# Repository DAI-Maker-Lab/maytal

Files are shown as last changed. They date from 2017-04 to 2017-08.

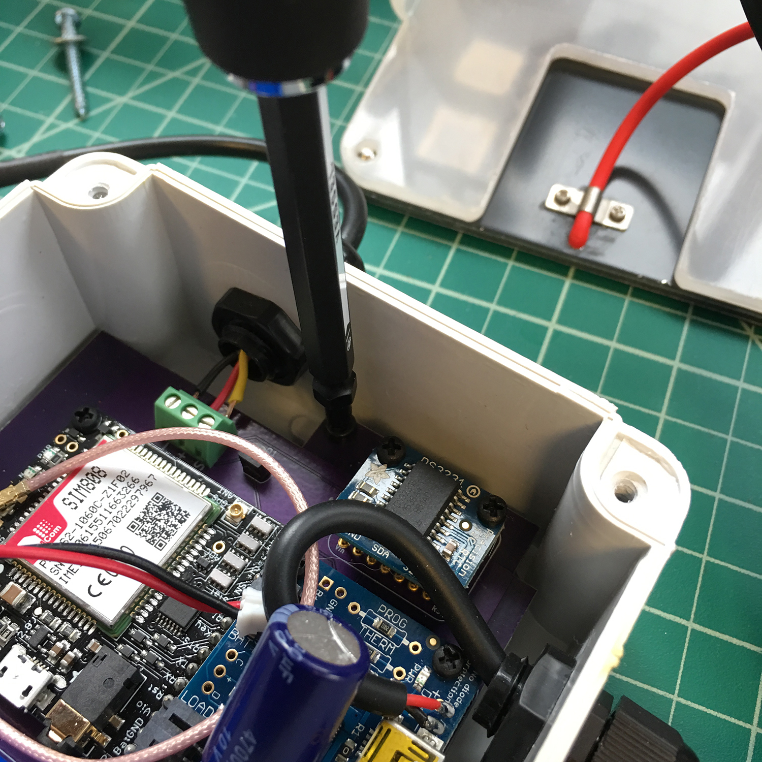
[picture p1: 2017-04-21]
photos/unscrew.jpg

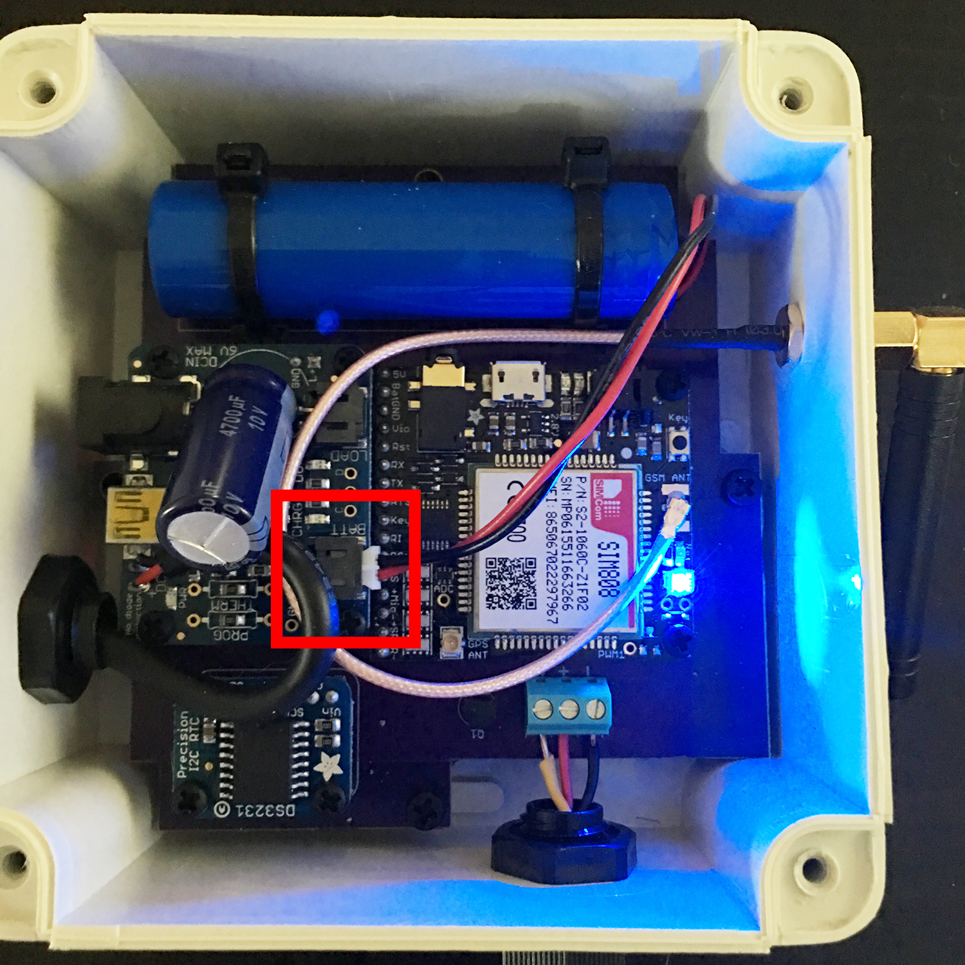
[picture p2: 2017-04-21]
photos/battery.jpg

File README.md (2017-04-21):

# Maytal
Maytal is the temporary name for an open source hardware project that aims to empower local Indonesian water utilities (PDAMs) to track pressure throughout their distribution systems, enabling them to operate more efficiently. The current design is a proof-of-concept prototype to test initial parameters and constraints. The bill of materials cost is about $180 and most parts are available locally in Indonesia.

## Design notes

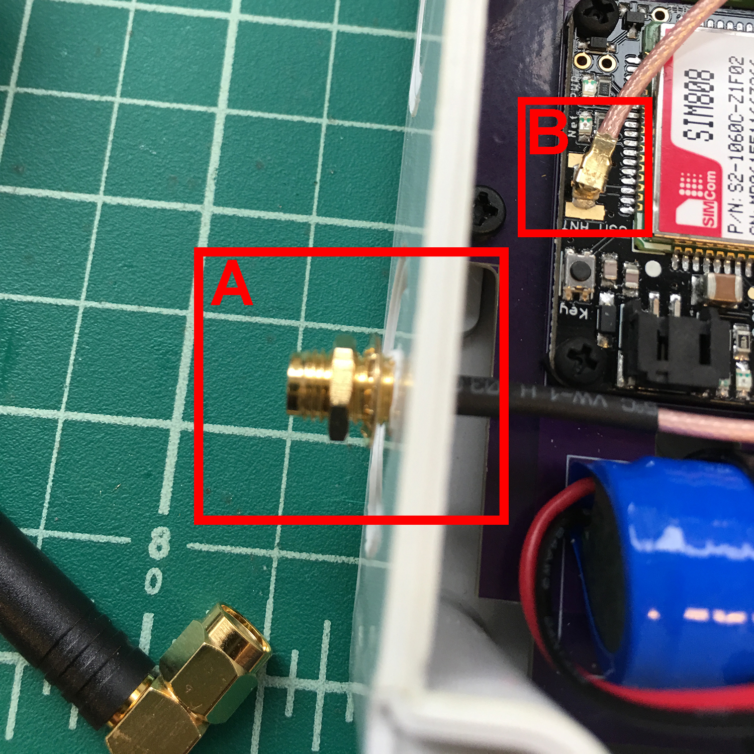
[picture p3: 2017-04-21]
photos/antenna.jpg

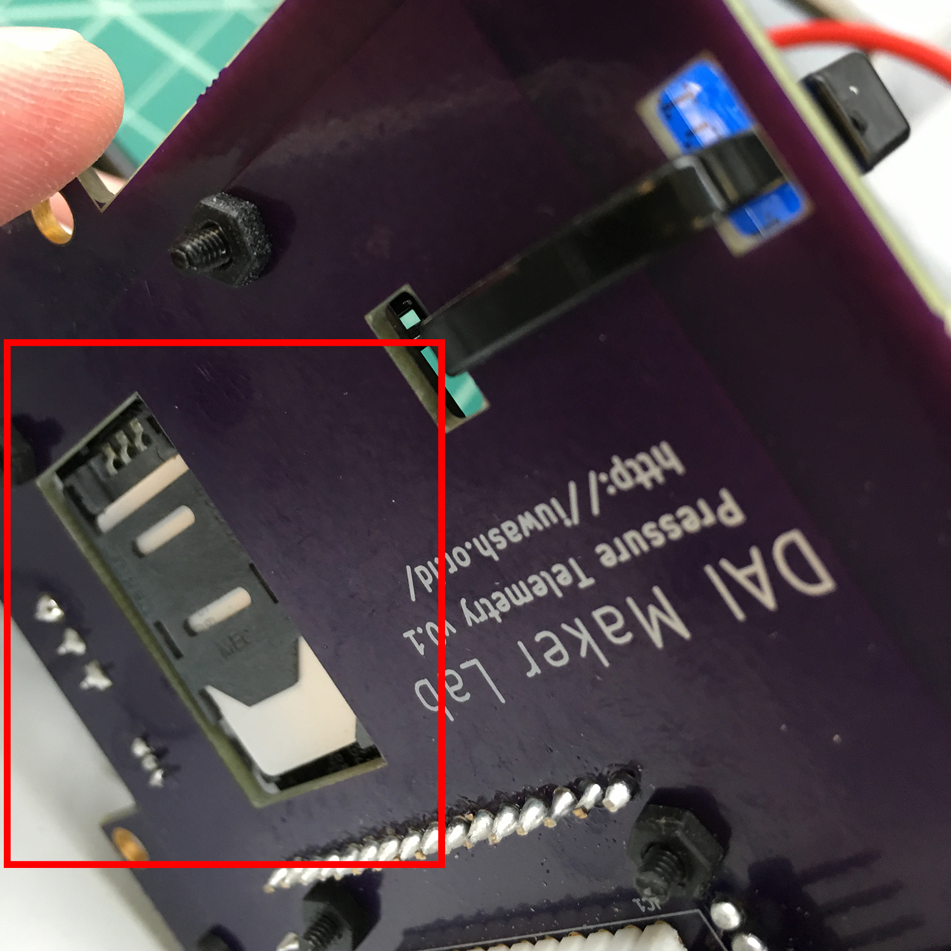
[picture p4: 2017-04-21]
photos/sim.jpg

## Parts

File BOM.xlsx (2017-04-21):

 | US | US Source | Indonesia | Indonesian Source
Arduino Mini | $9.95 | https://www.adafruit.com/products/2378 | IDR 215000.00 | http://www.geraicerdas.com/mikrokontroler/arduino-compatible/dfrduino-pro-mini-atmega328-detail
Adafruit FONA 808 | $49.95 | https://www.adafruit.com/products/2542 | IDR 720000.00 | https://m.tokopedia.com/akhishop/adafruit-fona-808-mini-cellular-gsm-gps-breakout
Adafruit LiPo Charger | $17.50 | https://www.adafruit.com/products/390 | IDR 175000.00 | http://www.geraicerdas.com/power-supply/lipo-rider-detail
RTC Breakout | $13.95 | https://www.adafruit.com/products/3013 | IDR 69000.00 | http://www.famosastudio.com/real-time-clock-module-v1.1
Solar Panel | $39.00 | https://www.adafruit.com/products/500 | ?? | ??
LiPo Battery | $9.95 | https://www.adafruit.com/products/1781 | IDR 33600.00 | https://www.tokopedia.com/rumah-kebutuhan/hame-lithium-ion-cylindrical-battery-37v-2200mah-with-flat-top-1
Pressure Transducer | $9.58 | https://www.aliexpress.com/item/New-Electric-Unit-Pressure-Transducer-Sensor-Oil-Fuel-for-Gas-Water-Air-Easy-removal-Carbon-Steel/32673407346.html | IDR 129330.00 | https://www.aliexpress.com/item/New-Electric-Unit-Pressure-Transducer-Sensor-Oil-Fuel-for-Gas-Water-Air-Easy-removal-Carbon-Steel/32673407346.html
Custom PCB | $23.10 | https://oshpark.com/ | ?? | ??
Terminal Block | $1.73 | https://www.digikey.com/product-detail/en/phoenix-contact/1751251/277-5749-ND/2511152 | ?? | ??
Enclosure | $4.07 | Glodok | IDR 55000.00 | Glodok
Total | $178.78 |  | IDR 1396930.00

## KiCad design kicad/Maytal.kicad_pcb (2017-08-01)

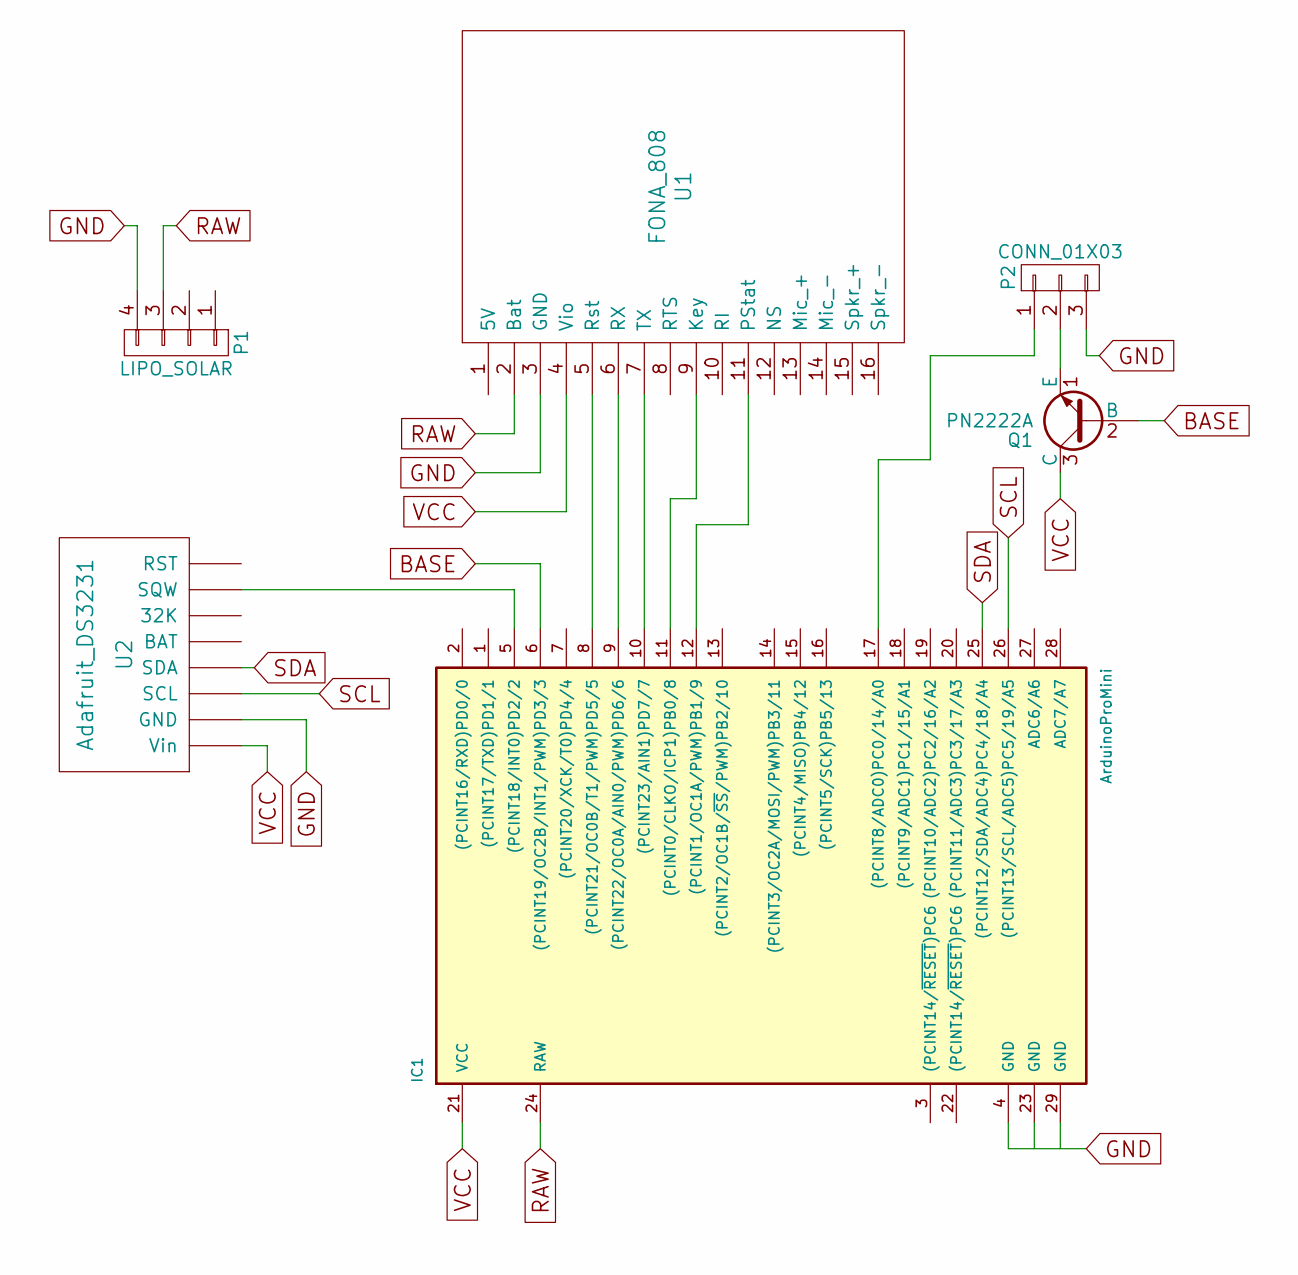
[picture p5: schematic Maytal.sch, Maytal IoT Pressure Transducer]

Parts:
IC1: ArduinoProMini; Arduino_Pro_Mini
P1: LIPO_SOLAR; Adafruit_LiPo_Solar
P2: CONN_01X03; TerminalBlock_Pheonix_PT-3.5mm_3pol
Q1: PN2222A; TO-92_Inline_Narrow_Oval
U1: FONA_808
U2: Adafruit_DS3231

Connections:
BASE: IC1.6 ((PCINT19/OC2B/INT1/PWM)PD3/3), Q1.2 (B)
GND: IC1.4 (GND), P1.4, P2.3, U1.3 (GND), U2.2 (GND)
unnamed: IC1.5 ((PCINT18/INT0)PD2/2), U2.7 (SQW)
unnamed: IC1.8 ((PCINT21/OC0B/T1/PWM)PD5/5), U1.5 (Rst)
unnamed: IC1.9 ((PCINT22/OC0A/AIN0/PWM)PD6/6), U1.6 (RX)
unnamed: IC1.10 ((PCINT23/AIN1)PD7/7), U1.7 (TX)
unnamed: IC1.11 ((PCINT0/CLKO/ICP1)PB0/8), U1.9 (Key)
unnamed: IC1.12 ((PCINT1/OC1A/PWM)PB1/9), U1.11 (PStat)
unnamed: IC1.17 ((PCINT8/ADC0)PC0/14/A0), P2.1
unnamed: P2.2, Q1.1 (E)
RAW: IC1.24 (RAW), P1.3, U1.2 (Bat)
SCL: IC1.26 ((PCINT13/SCL/ADC5)PC5/19/A5), U2.3 (SCL)
SDA: IC1.25 ((PCINT12/SDA/ADC4)PC4/18/A4), U2.4 (SDA)
VCC: IC1.21 (VCC), Q1.3 (C), U1.4 (Vio), U2.1 (Vin)

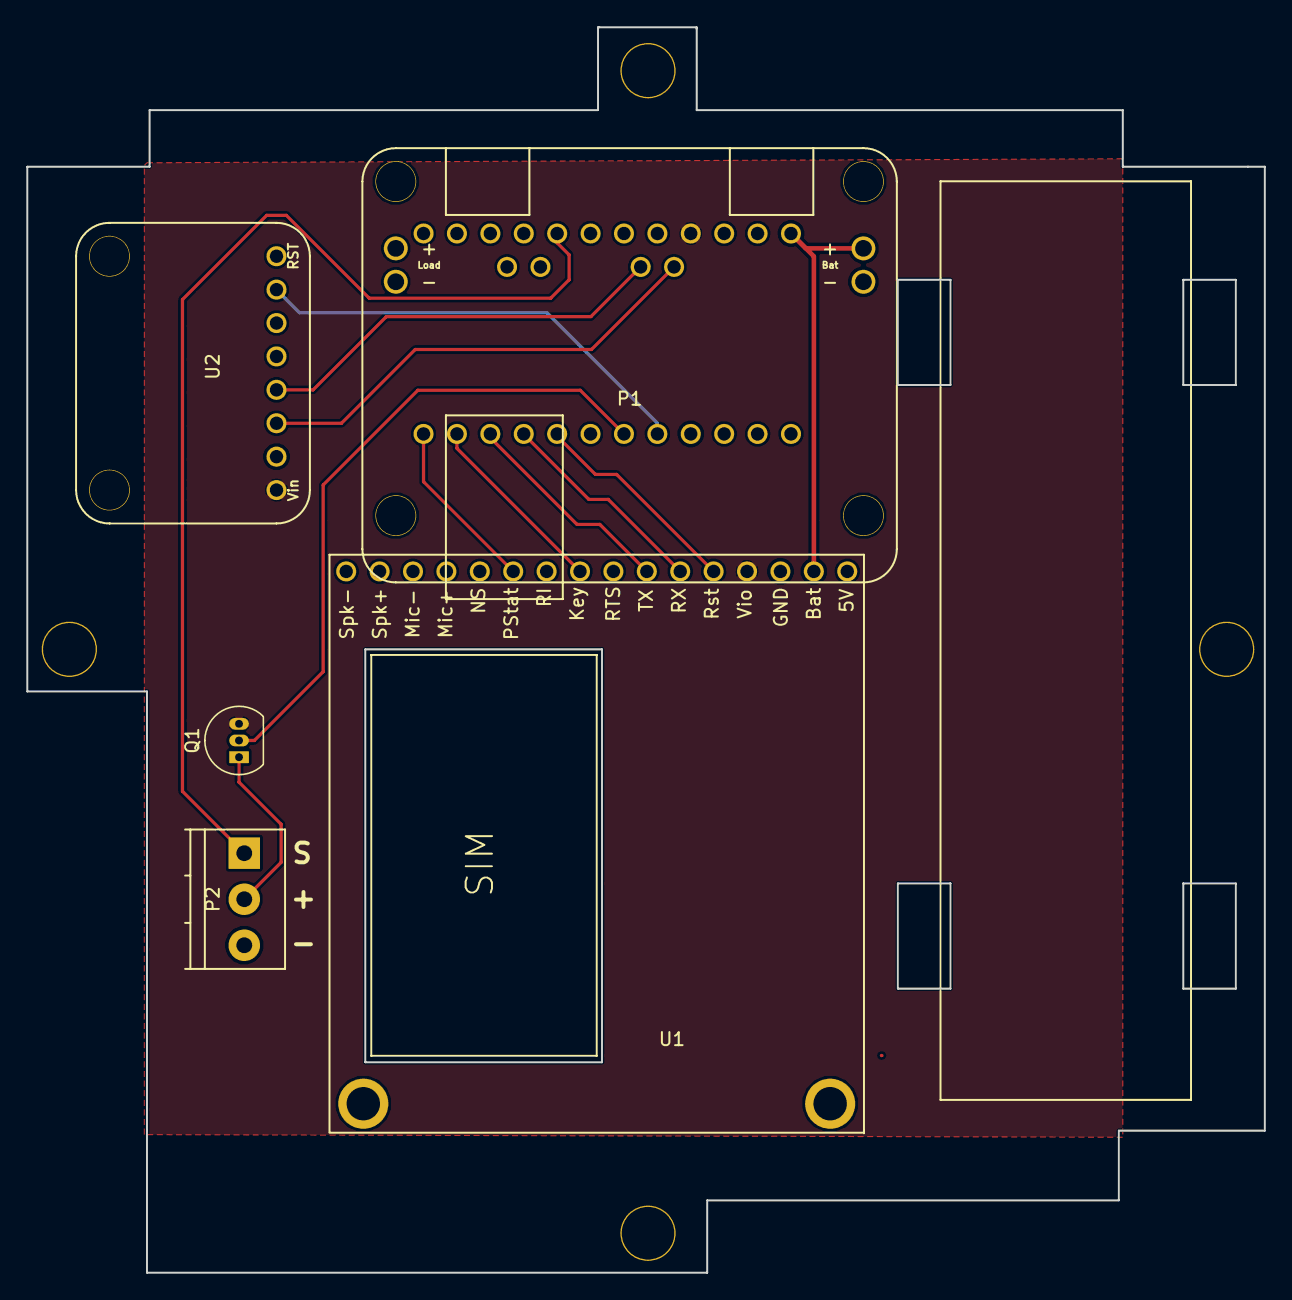
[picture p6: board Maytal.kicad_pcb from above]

Board: 2 copper layers, 94.1 x 94.7 mm, 6 parts (1 on the bottom side), 14 nets.

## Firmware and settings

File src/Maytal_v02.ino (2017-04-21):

#define VERSION "0.02"
#define UTCOFFSET -5          //  Local standard time variance from UTC
#define INTERVAL 15           //  Number of minutes between readings
#define PUBLIC_KEY "XXXXXX"   //  Public key for phant stream
#define PRIVATE_KEY "XXXXXX"  //  Private key for phant stream
//- - - - - - - - - - - - - - - - - - - - - -

#include <Adafruit_FONA.h>    //  https://github.com/adafruit/Adafruit_FONA
#include <DS3232RTC.h>        //  https://github.com/JChristensen/DS3232RTC
#include <Sleep_n0m1.h>       //  https://github.com/n0m1/Sleep_n0m1
#include <SoftwareSerial.h>   //  Standard software serial library
#include <TimeLib.h>          //  Standard time library
#include <Wire.h>             //  Standard wire library for comms with RTC



#define PRESSURE_PIN A0       //  Pressure reading pin from transducer
#define RTC_INTERRUPT_PIN 2   //  Square wave pin from RTC
#define Q1 3                  //  Base pin for transducer switch
#define FONA_RST 5            //  FONA reset pin
#define FONA_RX 6             //  UART pin to FONA
#define FONA_TX 7             //  UART pin from FONA
#define FONA_KEY 8            //  FONA Key pin
#define FONA_PS 9             //  FONA power status pin

time_t currentTime;
int lastPressure = 0;
boolean sentData = false;



Adafruit_FONA fona = Adafruit_FONA (FONA_RST);
SoftwareSerial fonaSerial = SoftwareSerial (FONA_TX, FONA_RX);

Sleep sleep;




static void rtcIRQ()
{
      RTC.alarm(ALARM_1);
}



void setup()
{
      pinMode(RTC_INTERRUPT_PIN, INPUT_PULLUP);
      pinMode(FONA_KEY, OUTPUT);
      pinMode(FONA_RX, OUTPUT);
      pinMode(Q1, OUTPUT);
      
      Serial.begin(57600);
      Serial.println();
      Serial.print(F("Maytal v"));
      Serial.println(VERSION);
      Serial.print(__DATE__);   //  Compile data and time helps identify software uploads
      Serial.print(F(" "));
      Serial.println(__TIME__);

      digitalWrite(Q1, LOW);    //  Turn off transducer to save power

      fonaOn();
      clockSet();
        
      //  Delete any accumulated SMS messages to avoid interference from old commands
      //fona.sendCheckReply (F("AT+CMGF=1"), F("OK"));            //  Enter text mode
      //fona.sendCheckReply (F("AT+CMGDA=\"DEL ALL\""), F("OK")); //  Delete all SMS messages
        
      fonaOff();

      //  Set up the RTC interrupts on every minute at the 00 second mark
      RTC.squareWave(SQWAVE_NONE);
      RTC.setAlarm(ALM1_MATCH_SECONDS, 0, 0, 0, 1);
      RTC.alarm(ALARM_1);
      RTC.alarmInterrupt(ALARM_1, true);
      attachInterrupt(digitalPinToInterrupt(RTC_INTERRUPT_PIN), rtcIRQ, FALLING);
      interrupts();
}



void loop()
{
      currentTime = RTC.get();
      
      Serial.print(hour(currentTime));
      Serial.print(F(":"));
      if(minute(currentTime) < 10)
      {
              Serial.print(F("0"));
      }
      Serial.println(minute(currentTime));
      
      int currentPressure = readPressure();

      Serial.println(currentPressure);
      
      //  If pressure has changed more than 10% since last upload, upload new reading
      if(((lastPressure*100)-(currentPressure*100))/currentPressure >= 10)
      {
              sendPressure(currentPressure);
      }

      //  If it is time to send a scheduled reading, send it
      if (minute(currentTime) % INTERVAL == 0 && sentData == false)
      {
              if(sendPressure(currentPressure) == true)
              {
                      sentData = true;
              }
      }
      else
      {
              sentData = false;
      }
      
      Serial.flush();         //  Flush any serial output before sleep
      RTC.setAlarm(ALM1_MATCH_SECONDS, 0, 0, 0, 1);
      RTC.alarm(ALARM_1);     //  Clear any outstanding RTC alarms
      RTC.alarmInterrupt(ALARM_1, true);
      sleep.pwrDownMode();
      wait(500);
      sleep.sleepInterrupt(digitalPinToInterrupt(RTC_INTERRUPT_PIN), FALLING); //  Sleep; wake on falling voltage on RTC pin
}



boolean fonaOn()
{
        if(digitalRead(FONA_PS) == LOW)             //  If the FONA is off...
        {
                Serial.print(F("Powering FONA on..."));
                while (digitalRead(FONA_PS) == LOW) 
                {
                        digitalWrite(FONA_KEY, LOW);  //  ...pulse the Key pin low...
                        wait(500);
                }
                digitalWrite(FONA_KEY, HIGH);        //  ...and then return it to high
                Serial.println(F(" done."));
        }
        
        Serial.println(F("Initializing FONA..."));
        
        fonaSerial.begin(4800);                      //  Open a serial interface to FONA
        
        if(fona.begin(fonaSerial) == false)         //  Start the FONA on serial interface
        {
                Serial.println(F("FONA not found. Check wiring and power."));
                return false;
        }
        else
        {
                Serial.print(F("FONA online. "));
                
                unsigned long gsmTimeout = millis() + 30000;
                boolean gsmTimedOut = false;

                Serial.print(F("Waiting for GSM network... "));
                while(1)
                {
                        byte network_status = fona.getNetworkStatus();
                        if(network_status == 1 || network_status == 5) break;
                        
                        if(millis() >= gsmTimeout)
                        {
                                gsmTimedOut = true;
                                break;
                        }
                        
                        wait(250);
                }

                if(gsmTimedOut == true)
                {
                        Serial.println(F("timed out. Check SIM card, antenna, and signal."));
                        return false;
                }
                else
                {
                        Serial.println(F("done."));
                }

                //  RSSI is a measure of signal strength -- higher is better; less than 10 is worrying
                byte rssi = fona.getRSSI();
                Serial.print(F("RSSI: "));
                Serial.println(rssi);

                wait(3000);    //  Give the network a moment

                //fona.setGPRSNetworkSettings(F("cellcard"));    //  Set APN to your local carrier

                if(rssi > 5)
                {
                        if(fona.enableGPRS(true) == false);
                        {
                              //  Sometimes enableGPRS() returns false even though it succeeded
                              if(fona.GPRSstate() != 1)
                              {
                                      for(byte GPRSattempts = 0; GPRSattempts < 5; GPRSattempts++)
                                      {
                                            Serial.println(F("Trying again..."));
                                            wait(2000);
                                            fona.enableGPRS(true);
                                            
                                            if(fona.GPRSstate() == 1)
                                            {
                                                    Serial.println(F("GPRS is on."));
                                                    break;
                                            }
                                            else
                                            {
                                                    Serial.print(F("Failed to turn GPRS on... "));
                                            }
                                      }
                              }
                        }
                }
                else
                {
                        Serial.println(F("Can't transmit, network signal strength is poor."));
                        gsmTimedOut = true;
                }
                
                return true;
        }
}



void clockSet()
{
        char method;
        
        wait(1000);    //  Give time for any trailing data to come in from FONA

        int netOffset;

        char theDate[17];

        Serial.println(F("Attempting to get time from GSM location service..."));

        flushFona();    //  Flush any trailing data

        fona.sendCheckReply(F("AT+CIPGSMLOC=2,1"), F("OK"));    //  Query GSM location service for time
        
        fona.parseInt();                    //  Ignore first int
        int secondInt = fona.parseInt();    //  Ignore second int -- necessary on some networks/towers
        int netYear = fona.parseInt();      //  Get the results -- GSMLOC year is 4-digit
        int netMonth = fona.parseInt();
        int netDay = fona.parseInt();
        int netHour = fona.parseInt();      //  GSMLOC is _supposed_ to get UTC; we will adjust
        int netMinute = fona.parseInt();
        int netSecond = fona.parseInt();    //  Our seconds may lag slightly, of course

        if(netYear < 2016 || netYear > 2050 || netHour > 23) //  If that obviously didn't work...
        {
                netSecond = netMinute;  //  ...shift everything up one to capture that second int
                netMinute = netHour;
                netHour = netDay;
                netDay = netMonth;
                netMonth = netYear;
                netYear = secondInt;

                Serial.println(F("Recombobulating..."));
        }

        if(netYear < 2016 || netYear > 2050 || netHour > 23)   // If that still didn't work...
        {
                Serial.println(F("GSM location service failed."));
                /*   ...the we'll get time from the NTP pool instead: 
                 *  (https://en.wikipedia.org/wiki/Network_Time_Protocol)
                 */
                fona.enableNTPTimeSync(true, F("0.daimakerlab.pool.ntp.org"));
                Serial.println(F("Attempting to enable NTP sync."));
                
                wait(15000);                 // Wait for NTP server response
                
                fona.println(F("AT+CCLK?")); // Query FONA's clock for resulting NTP time              
                netYear = fona.parseInt();    // Capture the results
                netMonth = fona.parseInt();
                netDay = fona.parseInt();
                netHour = fona.parseInt();    // We asked NTP for UTC and will adjust below
                netMinute = fona.parseInt();
                netSecond = fona.parseInt();  // Our seconds may lag slightly
        
                method = 'N';
        }
        else 
        {
                method = 'G';
        }

        if((netYear < 1000 && netYear >= 16 && netYear < 50) || (netYear > 1000 && netYear >= 2016 && netYear < 2050))
        //  If we got something that looks like a valid date...
        {
                //  Adjust UTC to local time
                if((netHour + UTCOFFSET) < 0)                   //  If our offset + the UTC hour < 0...
                {
                        netHour = (24 + netHour + UTCOFFSET);   //  ...add 24...
                        netDay = (netDay - 1);                  //  ...and adjust the date to UTC - 1
                }
                else
                {
                        if((netHour + UTCOFFSET) > 23)          //  If our offset + the UTC hour > 23...
                        {
                                netHour = (netHour + UTCOFFSET - 24); //  ...subtract 24...
                                netDay = (netDay + 1);                //  ...and adjust the date to UTC + 1
                        }
                        else
                        {
                                netHour = (netHour + UTCOFFSET);      //  Otherwise it's straight addition
                        }
                }

                Serial.print(F("Obtained current time: "));
                sprintf(theDate, "%d/%d/%d %d:%d", netDay, netMonth, netYear, netHour, netMinute);
                Serial.println(theDate);
                
                Serial.println(F("Adjusting RTC."));

                setTime(netHour, netMinute, netSecond, netDay, netMonth, netYear);   //set the system time to 23h31m30s on 13Feb2009
                RTC.set(now());                     //set the RTC from the system time
        }
        else
        {
                Serial.println(F("Didn't find reliable time. Will continue to use RTC's current time."));
                method = 'X';
        }

        wait(200);              //  Give FONA a moment to catch its breath
}



void flushFona()
{
        // Read all available serial input from FONA to flush any pending data.
        while(fona.available())
        {
                char c = fona.read();
                Serial.print(c);
        }
}



void fonaOff()
{
        wait(5000);        //  Shorter delays yield unpredictable results

        //  We'll turn GPRS off first, just to have an orderly shutdown
        if(fona.enableGPRS(false) == false)
        {
                if(fona.GPRSstate() == 1)
                {
                        Serial.println(F("Failed to turn GPRS off."));
                }
                else
                {
                        Serial.println(F("GPRS is off."));
                }
        }
      
        wait(500);
      
        // Power down the FONA if it needs it
        if(digitalRead(FONA_PS) == HIGH)      //  If the FONA is on...
        {
                fona.sendCheckReply(F("AT+CPOWD=1"), F("OK")); //  ...send shutdown command...
                digitalWrite(FONA_KEY, HIGH);                  //  ...and set Key high
        }
}



void wait(unsigned int ms)  //  Non-blocking delay function
{
      unsigned long period = millis() + ms;
      while(millis() < period)
      {
            Serial.flush();
      }
}



int readPressure()
{
      digitalWrite(Q1, HIGH);     //  Switch on transducer
      wait(3000);                 //  Let transducer settle
      
      float pressure = 0.00;
      int rawPressure = analogRead(PRESSURE_PIN);

      //  Validate that analogRead is between 0.5v-4.5v range of transducer
      if(rawPressure < 102 || rawPressure > 922)
      {
              pressure = 0;
      }
      else
      {
              pressure = ((rawPressure - 102.4) / 4.708);  //  Convert to PSI
      }

      digitalWrite(Q1, LOW);      //  Switch off transducer to save power

      return(int)pressure;
}



boolean sendPressure(int pressure)
{
      fonaOn();
      
      Serial.println(F("Sending pressure reading..."));

      char url[255];
      
      unsigned int voltage;
      fona.getBattVoltage(&voltage);   //  Read the battery voltage from FONA's ADC

      //  Generate the HTTP GET URL for the Phant server 
      sprintf(url, "data.sparkfun.com/input/%s?private_key=%s&pressure=%d&voltage=%d", PUBLIC_KEY, PRIVATE_KEY, pressure, voltage);
      Serial.print(F("Sending: "));
      Serial.println(url);

      unsigned int httpStatus;
      unsigned int datalen;

      boolean success = false;
      int attempts = 0;

      wait(7500);    //  A long delay here seems to improve reliability

      while(success == false && attempts < 5)   //  We'll attempt up to five times to upload data
      {
              fona.HTTP_GET_start(url, &httpStatus, &datalen);
              fona.HTTP_GET_end();
      
              if(httpStatus == 200)    //  If the HTTP GET request returned a 200, it succeeded
              {
                      Serial.println(F("Upload succeeded."));
                      success = true;
              }
              else
              {
                      Serial.println(F("Upload failed."));
                      success = false;
              }

              /*   Occasionally the FONA returns something other than a 200 even though the upload
               *   succeeded -- maybe that's coming from the server and maybe it isn't -- and so 
               *   you get a duplicate reading sent to Phant. It's not very common, but it does happen.
               */

              attempts++;

              wait(1000);
      }
      
      lastPressure = pressure;

      fonaOff();
      
      return success;
}
